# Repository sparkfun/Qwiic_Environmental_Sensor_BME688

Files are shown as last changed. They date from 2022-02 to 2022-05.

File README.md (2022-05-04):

SparkFun Environmental Sensor - BME688 (Qwiic)
========================================

SparkFun Environmental Sensor - BME688 (Qwiic) (https://www.sparkfun.com/products/19096)

[*SparkFun Environmental Sensor - BME688 (Qwiic) (SEN-19096)*](https://www.sparkfun.com/products/19096)

The SparkFun Environmental Sensor - BME688 (Qwiic) is a breakout board that combines a gas scanning sensor with temperature, humidity, and barometric pressure sensing for a complete environmental sensor in a single package. The gas sensor on the BME688 can detect a wide variety of volatile organic compounds (VOCs), volatile sulfur compounds (VSCs), and other gases such as carbon monoxide and hydrogen in the part per billion (ppb) range. Combine that with precise temperature, humidity, and barometric pressure and the BME688 can work as a completely standalone environmental sensor all in a 1in. x 1in. breakout!

The sensor communicates via either I2C or SPI. We've broken out the I2C pins to our Qwiic system so no soldering is required to connect it to the rest of your system but if you would prefer, both the I2C and SPI pins are also broken out to standard 0.1in.-spaced pins.

**Note:** While this sensor can be used with the BME AI-Studio and BSEC2 Arduino library; it is recommended for the AI functionality, users purchase the BME688 Evaluation Board (Coming Soon) for ease of use.

<p><div class="alert alert-warning"><b>Important:</b> In order to avoid contamination of its gas scanning capabilities, DO NOT touch the metallic casing of the BME688 sensor. Please, handle with care.</div></p>

_The SparkFun [Qwiic connect system](https://www.sparkfun.com/qwiic) is an ecosystem of I2C sensors, actuators, shields and cables that make prototyping faster and less prone to error. All Qwiic-enabled boards use a common 1mm pitch, 4-pin JST connector. This reduces the amount of required PCB space, and polarized connections mean you can’t hook it up wrong._

Repository Contents
-------------------

* **/Test Sketches** - Engineer's Arduino example code
* **/Hardware** - Eagle design files (.brd, .sch)
* **/Hardware/Production** - Production panel files (.brd)

Documentation
--------------

* **[Datasheet](https://www.bosch-sensortec.com/media/boschsensortec/downloads/datasheets/bst-bme688-ds000.pdf)** - BME688 Datasheet
* **[Hookup Guide](https://learn.sparkfun.com/tutorials/1168)** - SparkFun Environmental Sensor Breakout - BME68x (Qwiic) Hookup Guide
* **Arduino Libraries:**
    * **[BME680 Arduino Library](https://github.com/SV-Zanshin/BME680)** - Arduino Library used in Hookup Guide
    * **[BME68x Arduino Library](https://github.com/BoschSensortec/Bosch-BME68x-Library)** - Bosch's Arduino Library for BME68x Sensors
    * **[BSEC2 Arduino Library](https://github.com/BoschSensortec/Bosch-BSEC2-Library)** - Bosch's Arduino Library for BME AI-Studio
* **BME AI Studio:**
    * **BME AI-Studio (Mac/Windows)** *(Download from [Bosch software page](https://www.bosch-sensortec.com/software-tools/software/bme688-software/))*
    * **[BME AI-Studio Manual](https://www.bosch-sensortec.com/media/boschsensortec/downloads/application_notes_1/bst-bme688-an001.pdf)** - User Manual for BME AI-Studio

Product Versions
----------------
* [SEN-19096](https://www.sparkfun.com/products/19096) -  initial release

License Information
-------------------

This product is _**open source**_! 

Please review the LICENSE.md file for license information. 

If you have any questions or concerns on licensing, please contact technical support on our [SparkFun forums](https://forum.sparkfun.com/viewforum.php?f=152).

Distributed as-is; no warranty is given.

- Your friends at SparkFun.

_<COLLABORATION CREDIT>_

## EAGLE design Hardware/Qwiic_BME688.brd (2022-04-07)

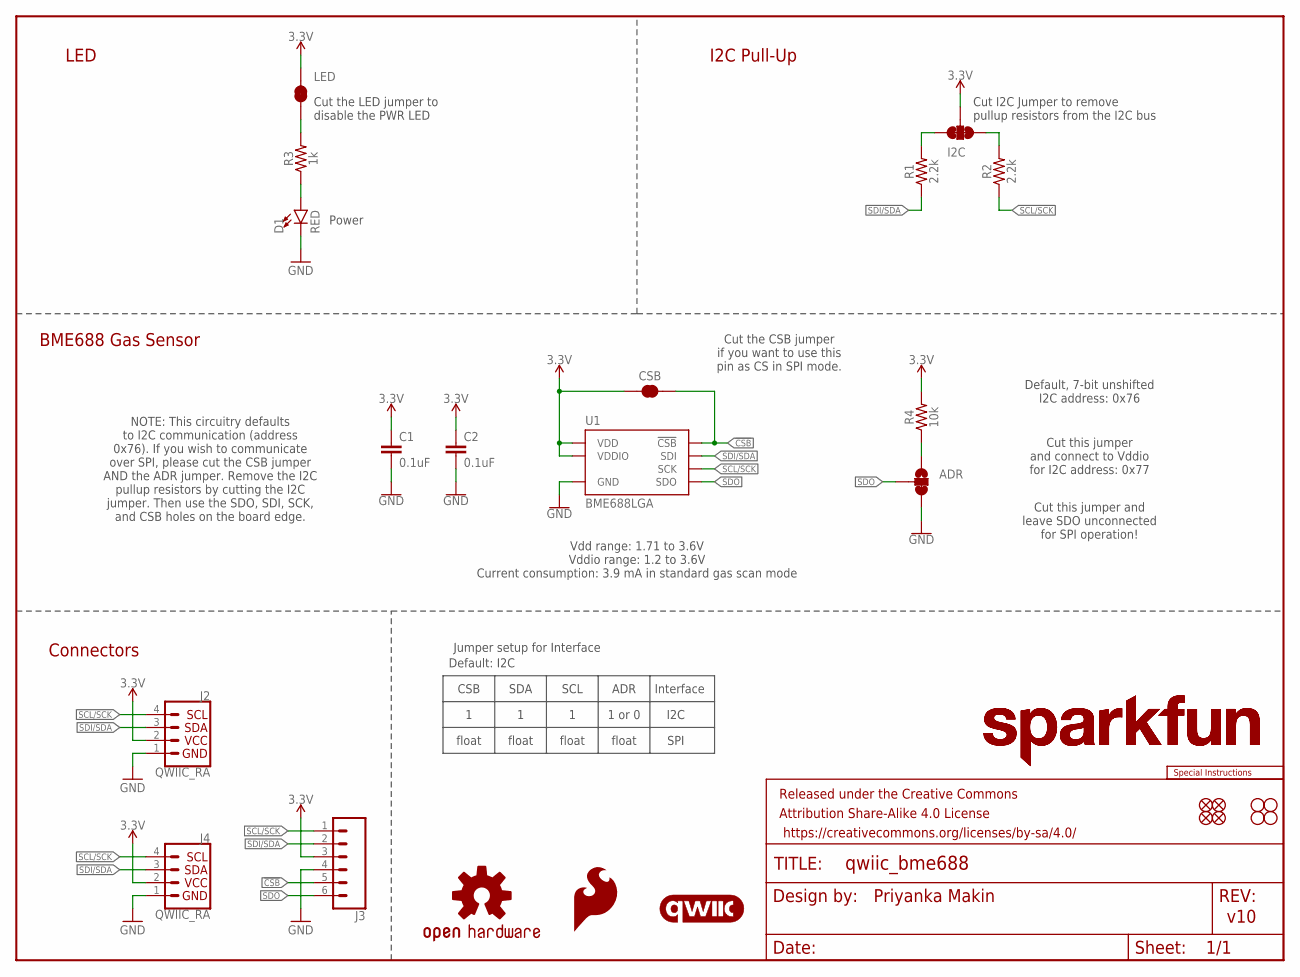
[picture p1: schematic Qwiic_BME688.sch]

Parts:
ADR: JUMPER-SMT_3_1-NC_TRACE_SILK; SMT-JUMPER_3_1-NC_TRACE_SILK
C1, C2: 0.1uF; 0603
CSB: JUMPER-SMT_2_NC_TRACE_SILK; SMT-JUMPER_2_NC_TRACE_SILK
D1: RED; LED-0603
FRAME1: FRAME-LETTER; CREATIVE_COMMONS
I2C: JUMPER-SMT_3_2-NC_TRACE_SILK; SMT-JUMPER_3_2-NC_TRACE_SILK
J2, J4: QWIIC_RA; JST04_1MM_RA
J3: CONN_06NO_SILK_NO_POP; 1X06_NO_SILK
JP1, JP2, JP5, JP6: FIDUCIALUFIDUCIAL; FIDUCIAL-MICRO
JP3, JP4, JP7, JP8: STAND-OFF
LED: JUMPER-SMT_2_NC_TRACE_SILK; SMT-JUMPER_2_NC_TRACE_SILK
LOGO1: SPECIAL_INSTRUCTIONS-ORDERING; ORDERING_INSTRUCTIONS
LOGO2: QWIIC_LOGO_5MM; QWIIC_5MM
LOGO3, LOGO6: SFE_LOGO_NAME.1_INCH; SFE_LOGO_NAME_.1
LOGO4: SFE_LOGO_FLAME.1_INCH; SFE_LOGO_FLAME_.1
LOGO5: OSHW-LOGOS; OSHW-LOGO-S
R1, R2: 2.2k; 0603
R3: 1k; 0603
R4: 10k; 0603
U1: BME688LGA; LGA_8PIN

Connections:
3.3V: C1.1, C2.1, CSB.1, I2C.2, J2.2, J3.3, J4.2, LED.2, R4.2, U1.6 (VDDIO), U1.8 (VDD)
!CSB!: CSB.2, J3.5, U1.2 (!CSB!)
GND: ADR.3, C1.2, C2.2, D1.C, J2.1, J3.4, J4.1, U1.1 (GND), U1.7 (GND)
unnamed: LED.1, R3.2
unnamed: I2C.3, R1.2
unnamed: D1.A, R3.1
unnamed: I2C.1, R2.2
unnamed: ADR.1, R4.1
SCL/SCK: J2.4, J3.1, J4.4, R2.1, U1.4 (SCK)
SDI/SDA: J2.3, J3.2, J4.3, R1.1, U1.3 (SDI)
SDO: ADR.2, J3.6, U1.5 (SDO)

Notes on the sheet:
v10
Default, 7-bit unshifted I2C address: 0x76
Power
I2C Pull-Up
BME688 Gas Sensor
Connectors
Cut the LED jumper to disable the PWR LED
Cut I2C Jumper to remove pullup resistors from the I2C bus
LED
Priyanka Makin
Vdd range: 1.71 to 3.6V Vddio range: 1.2 to 3.6V Current consumption: 3.9 mA in standard gas scan mode
Cut this jumper and connect to Vddio for I2C address: 0x77
Cut this jumper and leave SDO unconnected for SPI operation!
Cut the CSB jumper if you want to use this pin as CS in SPI mode.
NOTE: This circuitry defaults to I2C communication (address 0x76). If you wish to communicate over SPI, please cut the CSB jumper AND the ADR jumper. Remove the I2C pullup resistors by cutting the I2C jumper. Then use the SDO, SDI, SCK, and CSB holes on the board edge.
SCL
CSB
ADR
1 or 0
float
Interface
I2C
SPI
SDA
Jumper setup for Interface
Default: I2C

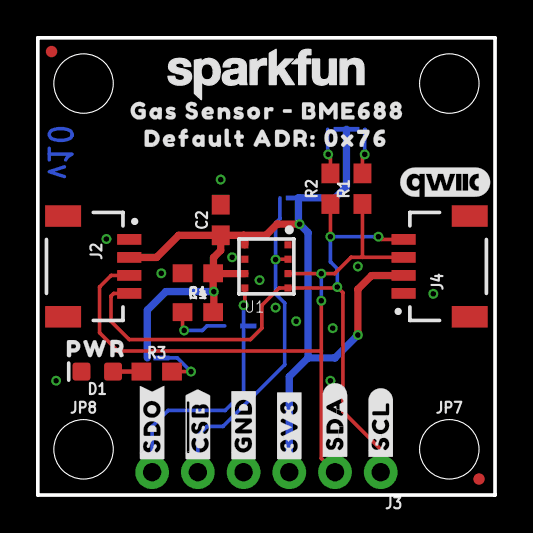
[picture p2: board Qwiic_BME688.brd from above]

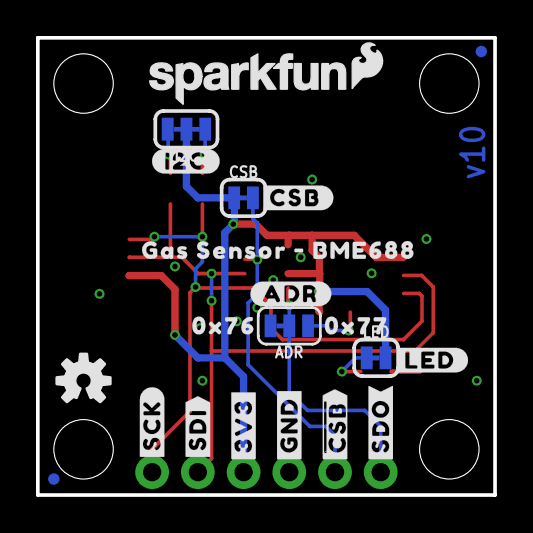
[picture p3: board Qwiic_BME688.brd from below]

Board: 2 copper layers, 25.4 x 25.4 mm, 52 parts (22 on the bottom side), 11 nets.

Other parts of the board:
U$1, U$33: #GND#0
U$2, U$16: #SDO#0
U$3: #CSB#0
U$5: PWR0
U$6: #I2C#0
U$7, U$10: GAS_SENSOR_#_BME6880
U$8: #LED#0
U$9: 0X760
U$11: #ADR#0
U$12: DEFAULT_ADR#_0X760
U$13: 0X770
U$14, U$15: #3V3#0
U$19: #SDI#0
U$20: #SCK#0
U$21, U$22: ##CSB##0
U$35: #SDA#0
U$36: #SCL#0

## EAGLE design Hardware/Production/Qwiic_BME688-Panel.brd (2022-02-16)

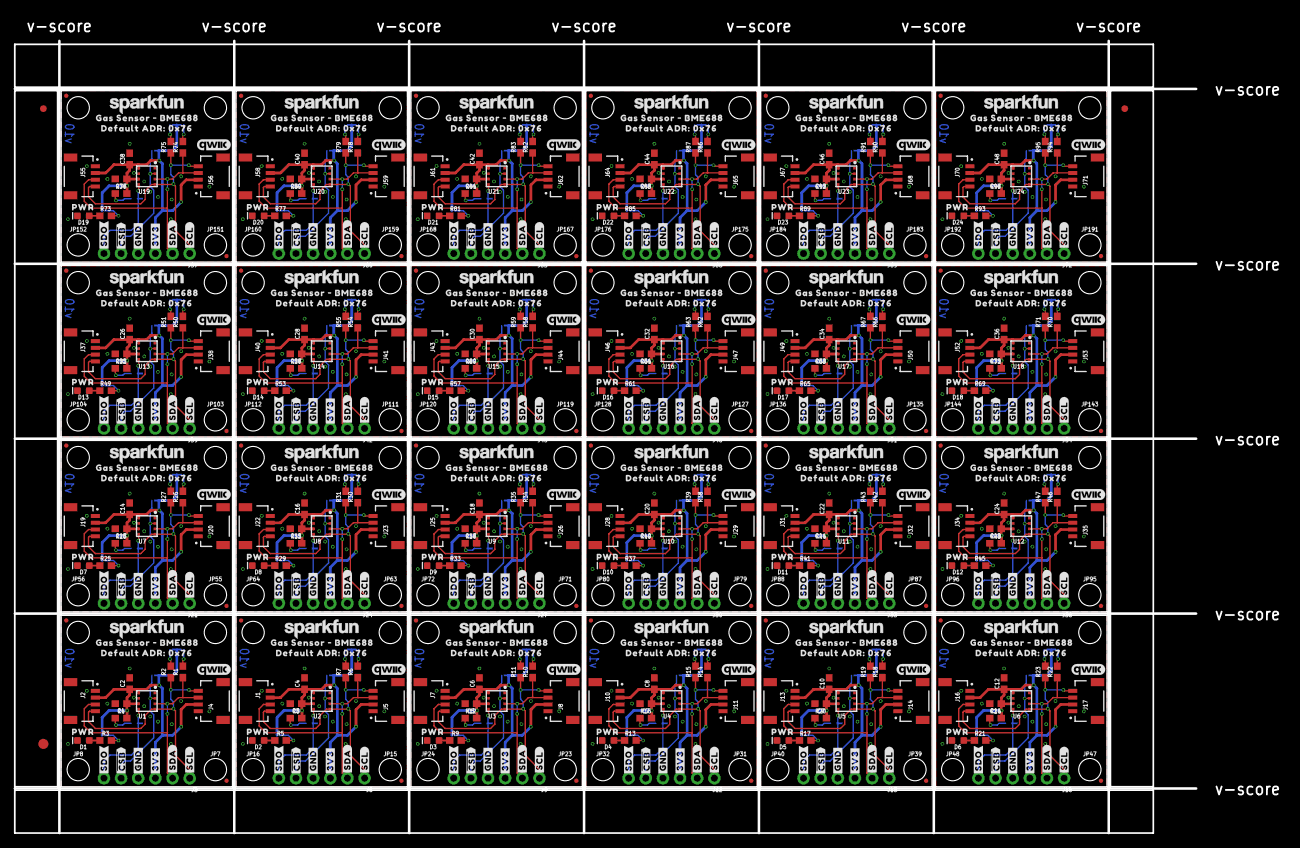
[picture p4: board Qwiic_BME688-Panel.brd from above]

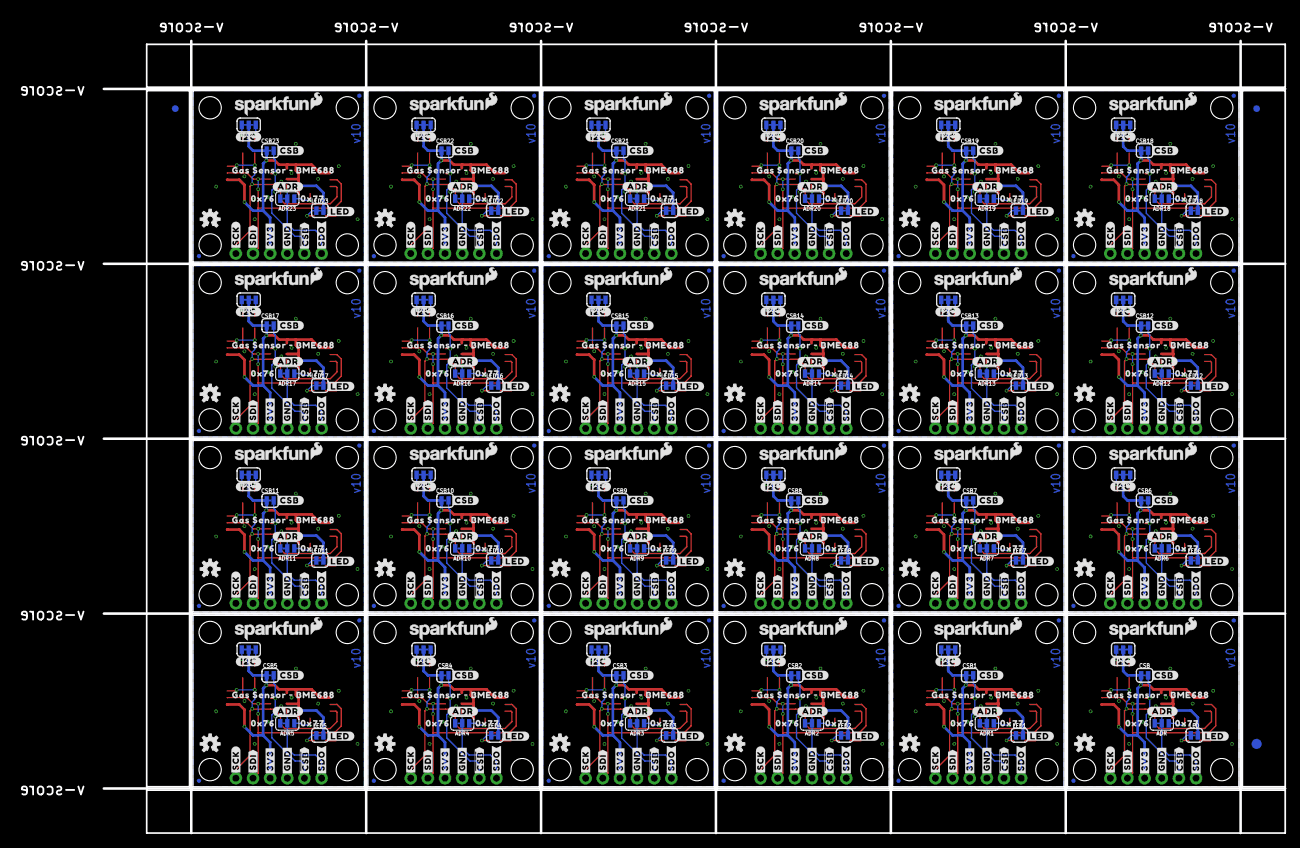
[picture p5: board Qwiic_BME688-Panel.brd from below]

Board: 2 copper layers, 175.0 x 117.3 mm, 1206 parts (531 on the bottom side), 264 nets.

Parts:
ADR, ADR1, ADR2, ADR3, ADR4, ADR5, ADR6, ADR7, ADR8, ADR9, ADR10, ADR11, ADR12, ADR13, ADR14, ADR15, ADR16, ADR17, ADR18, ADR19, ADR20, ADR21, ADR22, ADR23: JUMPER-SMT_3_1-NC_TRACE_SILK; SMT-JUMPER_3_1-NC_TRACE_SILK
C1, C2, C3, C4, C5, C6, C7, C8, C9, C10, C11, C12, C13, C14, C15, C16, C17, C18, C19, C20, C21, C22, C23, C24, C25, C26, C27, C28, C29, C30, C31, C32, C33, C34, C35, C36, C37, C38, C39, C40, C41, C42, C43, C44, C45, C46, C47, C48: 0.1uF; 0603
CSB, CSB1, CSB2, CSB3, CSB4, CSB5, CSB6, CSB7, CSB8, CSB9, CSB10, CSB11, CSB12, CSB13, CSB14, CSB15, CSB16, CSB17, CSB18, CSB19, CSB20, CSB21, CSB22, CSB23: JUMPER-SMT_2_NC_TRACE_SILK; SMT-JUMPER_2_NC_TRACE_SILK
D1, D2, D3, D4, D5, D6, D7, D8, D9, D10, D11, D12, D13, D14, D15, D16, D17, D18, D19, D20, D21, D22, D23, D24: RED; LED-0603
E$1, E$2, E$3, E$4: FIDUCIAL-1X2
E$5, E$6: FIDUCIAL-1.5X3
I2C, I2C1, I2C2, I2C3, I2C4, I2C5, I2C6, I2C7, I2C8, I2C9, I2C10, I2C11, I2C12, I2C13, I2C14, I2C15, I2C16, I2C17, I2C18, I2C19, I2C20, I2C21, I2C22, I2C23: JUMPER-SMT_3_2-NC_TRACE_SILK; SMT-JUMPER_3_2-NC_TRACE_SILK
J1, J2, J4, J5, J7, J8, J10, J11, J13, J14, J16, J17, J19, J20, J22, J23, J25, J26, J28, J29, J31, J32, J34, J35, J37, J38, J40, J41, J43, J44, J46, J47, J49, J50, J52, J53, J55, J56, J58, J59, J61, J62, J64, J65, J67, J68, J70, J71: QWIIC_RA; JST04_1MM_RA
J3, J6, J9, J12, J15, J18, J21, J24, J27, J30, J33, J36, J39, J42, J45, J48, J51, J54, J57, J60, J63, J66, J69, J72: 1X06_NO_SILK
JP1, JP2, JP5, JP6, JP11, JP12, JP13, JP14, JP19, JP20, JP21, JP22, JP27, JP28, JP29, JP30, JP35, JP36, JP37, JP38, JP43, JP44, JP45, JP46, JP51, JP52, JP53, JP54, JP59, JP60, JP61, JP62, JP67, JP68, JP69, JP70, JP75, JP76, JP77, JP78, JP83, JP84, JP85, JP86, JP91, JP92, JP93, JP94, JP99, JP100, JP101, JP102, JP107, JP108, JP109, JP110, JP115, JP116, JP117, JP118, JP123, JP124, JP125, JP126, JP131, JP132, JP133, JP134, JP139, JP140, JP141, JP142, JP147, JP148, JP149, JP150, JP155, JP156, JP157, JP158, JP163, JP164, JP165, JP166, JP171, JP172, JP173, JP174, JP179, JP180, JP181, JP182, JP187, JP188, JP189, JP190: FIDUCIALUFIDUCIAL; FIDUCIAL-MICRO
JP3, JP4, JP7, JP8, JP9, JP10, JP15, JP16, JP17, JP18, JP23, JP24, JP25, JP26, JP31, JP32, JP33, JP34, JP39, JP40, JP41, JP42, JP47, JP48, JP49, JP50, JP55, JP56, JP57, JP58, JP63, JP64, JP65, JP66, JP71, JP72, JP73, JP74, JP79, JP80, JP81, JP82, JP87, JP88, JP89, JP90, JP95, JP96, JP97, JP98, JP103, JP104, JP105, JP106, JP111, JP112, JP113, JP114, JP119, JP120, JP121, JP122, JP127, JP128, JP129, JP130, JP135, JP136, JP137, JP138, JP143, JP144, JP145, JP146, JP151, JP152, JP153, JP154, JP159, JP160, JP161, JP162, JP167, JP168, JP169, JP170, JP175, JP176, JP177, JP178, JP183, JP184, JP185, JP186, JP191, JP192: STAND-OFF
LED, LED1, LED2, LED3, LED4, LED5, LED6, LED7, LED8, LED9, LED10, LED11, LED12, LED13, LED14, LED15, LED16, LED17, LED18, LED19, LED20, LED21, LED22, LED23: JUMPER-SMT_2_NC_TRACE_SILK; SMT-JUMPER_2_NC_TRACE_SILK
LOGO1, LOGO5, LOGO11, LOGO16, LOGO21, LOGO26, LOGO31, LOGO36, LOGO41, LOGO46, LOGO51, LOGO56, LOGO61, LOGO66, LOGO71, LOGO76, LOGO81, LOGO86, LOGO91, LOGO96, LOGO101, LOGO106, LOGO111, LOGO116: OSHW-LOGOS; OSHW-LOGO-S
LOGO2, LOGO7, LOGO12, LOGO17, LOGO22, LOGO27, LOGO32, LOGO37, LOGO42, LOGO47, LOGO52, LOGO57, LOGO62, LOGO67, LOGO72, LOGO77, LOGO82, LOGO87, LOGO92, LOGO97, LOGO102, LOGO107, LOGO112, LOGO117: QWIIC_LOGO_5MM; QWIIC_5MM
LOGO3, LOGO6, LOGO8, LOGO10, LOGO13, LOGO15, LOGO18, LOGO20, LOGO23, LOGO25, LOGO28, LOGO30, LOGO33, LOGO35, LOGO38, LOGO40, LOGO43, LOGO45, LOGO48, LOGO50, LOGO53, LOGO55, LOGO58, LOGO60, LOGO63, LOGO65, LOGO68, LOGO70, LOGO73, LOGO75, LOGO78, LOGO80, LOGO83, LOGO85, LOGO88, LOGO90, LOGO93, LOGO95, LOGO98, LOGO100, LOGO103, LOGO105, LOGO108, LOGO110, LOGO113, LOGO115, LOGO118, LOGO120: SFE_LOGO_NAME.1_INCH; SFE_LOGO_NAME_.1
LOGO4, LOGO9, LOGO14, LOGO19, LOGO24, LOGO29, LOGO34, LOGO39, LOGO44, LOGO49, LOGO54, LOGO59, LOGO64, LOGO69, LOGO74, LOGO79, LOGO84, LOGO89, LOGO94, LOGO99, LOGO104, LOGO109, LOGO114, LOGO119: SFE_LOGO_FLAME.1_INCH; SFE_LOGO_FLAME_.1
R1, R2, R6, R7, R10, R11, R14, R15, R18, R19, R22, R23, R26, R27, R30, R31, R34, R35, R38, R39, R42, R43, R46, R47, R50, R51, R54, R55, R58, R59, R62, R63, R66, R67, R70, R71, R74, R75, R78, R79, R82, R83, R86, R87, R90, R91, R94, R95: 2.2k; 0603
R3, R5, R9, R13, R17, R21, R25, R29, R33, R37, R41, R45, R49, R53, R57, R61, R65, R69, R73, R77, R81, R85, R89, R93: 1k; 0603
R4, R8, R12, R16, R20, R24, R28, R32, R36, R40, R44, R48, R52, R56, R60, R64, R68, R72, R76, R80, R84, R88, R92, R96: 10k; 0603
U1, U2, U3, U4, U5, U6, U7, U8, U9, U10, U11, U12, U13, U14, U15, U16, U17, U18, U19, U20, U21, U22, U23, U24: BME688LGA; LGA_8PIN
U$1, U$4, U$23, U$33, U$45, U$48, U$67, U$70, U$89, U$92, U$111, U$114, U$133, U$136, U$155, U$158, U$177, U$180, U$199, U$202, U$221, U$224, U$243, U$246, U$265, U$268, U$287, U$290, U$309, U$312, U$331, U$334, U$353, U$356, U$375, U$378, U$397, U$400, U$419, U$422, U$441, U$444, U$463, U$466, U$485, U$488, U$507, U$510: #GND#0
U$2, U$16, U$38, U$39, U$60, U$61, U$82, U$83, U$104, U$105, U$126, U$127, U$148, U$149, U$170, U$171, U$192, U$193, U$214, U$215, U$236, U$237, U$258, U$259, U$280, U$281, U$302, U$303, U$324, U$325, U$346, U$347, U$368, U$369, U$390, U$391, U$412, U$413, U$434, U$435, U$456, U$457, U$478, U$479, U$500, U$501, U$522, U$523: #SDO#0
U$3, U$42, U$64, U$86, U$108, U$130, U$152, U$174, U$196, U$218, U$240, U$262, U$284, U$306, U$328, U$350, U$372, U$394, U$416, U$438, U$460, U$482, U$504, U$526: #CSB#0
U$5, U$24, U$49, U$71, U$93, U$115, U$137, U$159, U$181, U$203, U$225, U$247, U$269, U$291, U$313, U$335, U$357, U$379, U$401, U$423, U$445, U$467, U$489, U$511: PWR0
U$6, U$29, U$54, U$76, U$98, U$120, U$142, U$164, U$186, U$208, U$230, U$252, U$274, U$296, U$318, U$340, U$362, U$384, U$406, U$428, U$450, U$472, U$494, U$516: #I2C#0
U$7, U$10, U$25, U$27, U$50, U$52, U$72, U$74, U$94, U$96, U$116, U$118, U$138, U$140, U$160, U$162, U$182, U$184, U$204, U$206, U$226, U$228, U$248, U$250, U$270, U$272, U$292, U$294, U$314, U$316, U$336, U$338, U$358, U$360, U$380, U$382, U$402, U$404, U$424, U$426, U$446, U$448, U$468, U$470, U$490, U$492, U$512, U$514: GAS_SENSOR_#_BME6880
U$8, U$28, U$53, U$75, U$97, U$119, U$141, U$163, U$185, U$207, U$229, U$251, U$273, U$295, U$317, U$339, U$361, U$383, U$405, U$427, U$449, U$471, U$493, U$515: #LED#0
U$9, U$31, U$56, U$78, U$100, U$122, U$144, U$166, U$188, U$210, U$232, U$254, U$276, U$298, U$320, U$342, U$364, U$386, U$408, U$430, U$452, U$474, U$496, U$518: 0X760
U$11, U$26, U$51, U$73, U$95, U$117, U$139, U$161, U$183, U$205, U$227, U$249, U$271, U$293, U$315, U$337, U$359, U$381, U$403, U$425, U$447, U$469, U$491, U$513: #ADR#0
U$12, U$30, U$55, U$77, U$99, U$121, U$143, U$165, U$187, U$209, U$231, U$253, U$275, U$297, U$319, U$341, U$363, U$385, U$407, U$429, U$451, U$473, U$495, U$517: DEFAULT_ADR#_0X760
U$13, U$32, U$57, U$79, U$101, U$123, U$145, U$167, U$189, U$211, U$233, U$255, U$277, U$299, U$321, U$343, U$365, U$387, U$409, U$431, U$453, U$475, U$497, U$519: 0X770
U$14, U$15, U$34, U$37, U$58, U$59, U$80, U$81, U$102, U$103, U$124, U$125, U$146, U$147, U$168, U$169, U$190, U$191, U$212, U$213, U$234, U$235, U$256, U$257, U$278, U$279, U$300, U$301, U$322, U$323, U$344, U$345, U$366, U$367, U$388, U$389, U$410, U$411, U$432, U$433, U$454, U$455, U$476, U$477, U$498, U$499, U$520, U$521: #3V3#0
U$17, U$35, U$46, U$68, U$90, U$112, U$134, U$156, U$178, U$200, U$222, U$244, U$266, U$288, U$310, U$332, U$354, U$376, U$398, U$420, U$442, U$464, U$486, U$508: #SDA#0
U$18, U$36, U$47, U$69, U$91, U$113, U$135, U$157, U$179, U$201, U$223, U$245, U$267, U$289, U$311, U$333, U$355, U$377, U$399, U$421, U$443, U$465, U$487, U$509: #SCL#0
U$19, U$40, U$62, U$84, U$106, U$128, U$150, U$172, U$194, U$216, U$238, U$260, U$282, U$304, U$326, U$348, U$370, U$392, U$414, U$436, U$458, U$480, U$502, U$524: #SDI#0
U$20, U$41, U$63, U$85, U$107, U$129, U$151, U$173, U$195, U$217, U$239, U$261, U$283, U$305, U$327, U$349, U$371, U$393, U$415, U$437, U$459, U$481, U$503, U$525: #SCK#0
U$21, U$22, U$43, U$44, U$65, U$66, U$87, U$88, U$109, U$110, U$131, U$132, U$153, U$154, U$175, U$176, U$197, U$198, U$219, U$220, U$241, U$242, U$263, U$264, U$285, U$286, U$307, U$308, U$329, U$330, U$351, U$352, U$373, U$374, U$395, U$396, U$417, U$418, U$439, U$440, U$461, U$462, U$483, U$484, U$505, U$506, U$527, U$528: ##CSB##0

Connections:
3.3V: C1.1, C2.1, CSB.1, I2C.2, J2.2, J3.3, J4.2, LED.2, R4.2, U1.6, U1.8
3.3V1: C3.1, C4.1, CSB1.1, I2C1.2, J1.2, J5.2, J6.3, LED1.2, R8.2, U2.6, U2.8
3.3V2: C5.1, C6.1, CSB2.1, I2C2.2, J7.2, J8.2, J9.3, LED2.2, R12.2, U3.6, U3.8
3.3V3: C7.1, C8.1, CSB3.1, I2C3.2, J10.2, J11.2, J12.3, LED3.2, R16.2, U4.6, U4.8
3.3V4: C9.1, C10.1, CSB4.1, I2C4.2, J13.2, J14.2, J15.3, LED4.2, R20.2, U5.6, U5.8
3.3V5: C11.1, C12.1, CSB5.1, I2C5.2, J16.2, J17.2, J18.3, LED5.2, R24.2, U6.6, U6.8
3.3V6: C13.1, C14.1, CSB6.1, I2C6.2, J19.2, J20.2, J21.3, LED6.2, R28.2, U7.6, U7.8
3.3V7: C15.1, C16.1, CSB7.1, I2C7.2, J22.2, J23.2, J24.3, LED7.2, R32.2, U8.6, U8.8
3.3V8: C17.1, C18.1, CSB8.1, I2C8.2, J25.2, J26.2, J27.3, LED8.2, R36.2, U9.6, U9.8
3.3V9: C19.1, C20.1, CSB9.1, I2C9.2, J28.2, J29.2, J30.3, LED9.2, R40.2, U10.6, U10.8
3.3V10: C21.1, C22.1, CSB10.1, I2C10.2, J31.2, J32.2, J33.3, LED10.2, R44.2, U11.6, U11.8
3.3V11: C23.1, C24.1, CSB11.1, I2C11.2, J34.2, J35.2, J36.3, LED11.2, R48.2, U12.6, U12.8
3.3V12: C25.1, C26.1, CSB12.1, I2C12.2, J37.2, J38.2, J39.3, LED12.2, R52.2, U13.6, U13.8
3.3V13: C27.1, C28.1, CSB13.1, I2C13.2, J40.2, J41.2, J42.3, LED13.2, R56.2, U14.6, U14.8
3.3V14: C29.1, C30.1, CSB14.1, I2C14.2, J43.2, J44.2, J45.3, LED14.2, R60.2, U15.6, U15.8
3.3V15: C31.1, C32.1, CSB15.1, I2C15.2, J46.2, J47.2, J48.3, LED15.2, R64.2, U16.6, U16.8
3.3V16: C33.1, C34.1, CSB16.1, I2C16.2, J49.2, J50.2, J51.3, LED16.2, R68.2, U17.6, U17.8
3.3V17: C35.1, C36.1, CSB17.1, I2C17.2, J52.2, J53.2, J54.3, LED17.2, R72.2, U18.6, U18.8
3.3V18: C37.1, C38.1, CSB18.1, I2C18.2, J55.2, J56.2, J57.3, LED18.2, R76.2, U19.6, U19.8
3.3V19: C39.1, C40.1, CSB19.1, I2C19.2, J58.2, J59.2, J60.3, LED19.2, R80.2, U20.6, U20.8
3.3V20: C41.1, C42.1, CSB20.1, I2C20.2, J61.2, J62.2, J63.3, LED20.2, R84.2, U21.6, U21.8
3.3V21: C43.1, C44.1, CSB21.1, I2C21.2, J64.2, J65.2, J66.3, LED21.2, R88.2, U22.6, U22.8
3.3V22: C45.1, C46.1, CSB22.1, I2C22.2, J67.2, J68.2, J69.3, LED22.2, R92.2, U23.6, U23.8
3.3V23: C47.1, C48.1, CSB23.1, I2C23.2, J70.2, J71.2, J72.3, LED23.2, R96.2, U24.6, U24.8
!CSB!: CSB.2, J3.5, U1.2
!CSB!1: CSB1.2, J6.5, U2.2
!CSB!2: CSB2.2, J9.5, U3.2
!CSB!3: CSB3.2, J12.5, U4.2
!CSB!4: CSB4.2, J15.5, U5.2
!CSB!5: CSB5.2, J18.5, U6.2
!CSB!6: CSB6.2, J21.5, U7.2
!CSB!7: CSB7.2, J24.5, U8.2
!CSB!8: CSB8.2, J27.5, U9.2
!CSB!9: CSB9.2, J30.5, U10.2
!CSB!10: CSB10.2, J33.5, U11.2
!CSB!11: CSB11.2, J36.5, U12.2
!CSB!12: CSB12.2, J39.5, U13.2
!CSB!13: CSB13.2, J42.5, U14.2
!CSB!14: CSB14.2, J45.5, U15.2
!CSB!15: CSB15.2, J48.5, U16.2
!CSB!16: CSB16.2, J51.5, U17.2
!CSB!17: CSB17.2, J54.5, U18.2
!CSB!18: CSB18.2, J57.5, U19.2
!CSB!19: CSB19.2, J60.5, U20.2
!CSB!20: CSB20.2, J63.5, U21.2
!CSB!21: CSB21.2, J66.5, U22.2
!CSB!22: CSB22.2, J69.5, U23.2
!CSB!23: CSB23.2, J72.5, U24.2
GND: ADR.3, C1.2, C2.2, D1.C, J2.1, J3.4, J4.1, U1.1, U1.7
GND1: ADR1.3, C3.2, C4.2, D2.C, J1.1, J5.1, J6.4, U2.1, U2.7
GND2: ADR2.3, C5.2, C6.2, D3.C, J7.1, J8.1, J9.4, U3.1, U3.7
GND3: ADR3.3, C7.2, C8.2, D4.C, J10.1, J11.1, J12.4, U4.1, U4.7
GND4: ADR4.3, C9.2, C10.2, D5.C, J13.1, J14.1, J15.4, U5.1, U5.7
GND5: ADR5.3, C11.2, C12.2, D6.C, J16.1, J17.1, J18.4, U6.1, U6.7
GND6: ADR6.3, C13.2, C14.2, D7.C, J19.1, J20.1, J21.4, U7.1, U7.7
GND7: ADR7.3, C15.2, C16.2, D8.C, J22.1, J23.1, J24.4, U8.1, U8.7
GND8: ADR8.3, C17.2, C18.2, D9.C, J25.1, J26.1, J27.4, U9.1, U9.7
GND9: ADR9.3, C19.2, C20.2, D10.C, J28.1, J29.1, J30.4, U10.1, U10.7
GND10: ADR10.3, C21.2, C22.2, D11.C, J31.1, J32.1, J33.4, U11.1, U11.7
GND11: ADR11.3, C23.2, C24.2, D12.C, J34.1, J35.1, J36.4, U12.1, U12.7
GND12: ADR12.3, C25.2, C26.2, D13.C, J37.1, J38.1, J39.4, U13.1, U13.7
GND13: ADR13.3, C27.2, C28.2, D14.C, J40.1, J41.1, J42.4, U14.1, U14.7
GND14: ADR14.3, C29.2, C30.2, D15.C, J43.1, J44.1, J45.4, U15.1, U15.7
GND15: ADR15.3, C31.2, C32.2, D16.C, J46.1, J47.1, J48.4, U16.1, U16.7
GND16: ADR16.3, C33.2, C34.2, D17.C, J49.1, J50.1, J51.4, U17.1, U17.7
GND17: ADR17.3, C35.2, C36.2, D18.C, J52.1, J53.1, J54.4, U18.1, U18.7
GND18: ADR18.3, C37.2, C38.2, D19.C, J55.1, J56.1, J57.4, U19.1, U19.7
GND19: ADR19.3, C39.2, C40.2, D20.C, J58.1, J59.1, J60.4, U20.1, U20.7
GND20: ADR20.3, C41.2, C42.2, D21.C, J61.1, J62.1, J63.4, U21.1, U21.7
GND21: ADR21.3, C43.2, C44.2, D22.C, J64.1, J65.1, J66.4, U22.1, U22.7
GND22: ADR22.3, C45.2, C46.2, D23.C, J67.1, J68.1, J69.4, U23.1, U23.7
GND23: ADR23.3, C47.2, C48.2, D24.C, J70.1, J71.1, J72.4, U24.1, U24.7
unnamed: LED.1, R3.2
unnamed: I2C.3, R1.2
unnamed: D1.A, R3.1
unnamed: I2C.1, R2.2
unnamed: ADR.1, R4.1
unnamed: D2.A, R5.1
unnamed: LED1.1, R5.2
unnamed: I2C1.3, R6.2
unnamed: I2C1.1, R7.2
unnamed: ADR1.1, R8.1
unnamed: D3.A, R9.1
unnamed: LED2.1, R9.2
unnamed: I2C2.3, R10.2
unnamed: I2C2.1, R11.2
unnamed: ADR2.1, R12.1
unnamed: D4.A, R13.1
unnamed: LED3.1, R13.2
unnamed: I2C3.3, R14.2
unnamed: I2C3.1, R15.2
unnamed: ADR3.1, R16.1
unnamed: D5.A, R17.1
unnamed: LED4.1, R17.2
unnamed: I2C4.3, R18.2
unnamed: I2C4.1, R19.2
unnamed: ADR4.1, R20.1
unnamed: D6.A, R21.1
unnamed: LED5.1, R21.2
unnamed: I2C5.3, R22.2
unnamed: I2C5.1, R23.2
unnamed: ADR5.1, R24.1
unnamed: D7.A, R25.1
unnamed: LED6.1, R25.2
unnamed: I2C6.3, R26.2
unnamed: I2C6.1, R27.2
unnamed: ADR6.1, R28.1
unnamed: D8.A, R29.1
unnamed: LED7.1, R29.2
unnamed: I2C7.3, R30.2
unnamed: I2C7.1, R31.2
unnamed: ADR7.1, R32.1
unnamed: D9.A, R33.1
unnamed: LED8.1, R33.2
unnamed: I2C8.3, R34.2
unnamed: I2C8.1, R35.2
unnamed: ADR8.1, R36.1
unnamed: D10.A, R37.1
unnamed: LED9.1, R37.2
unnamed: I2C9.3, R38.2
unnamed: I2C9.1, R39.2
unnamed: ADR9.1, R40.1
unnamed: D11.A, R41.1
unnamed: LED10.1, R41.2
unnamed: I2C10.3, R42.2
unnamed: I2C10.1, R43.2
unnamed: ADR10.1, R44.1
unnamed: D12.A, R45.1
unnamed: LED11.1, R45.2
unnamed: I2C11.3, R46.2
unnamed: I2C11.1, R47.2
unnamed: ADR11.1, R48.1
unnamed: D13.A, R49.1
unnamed: LED12.1, R49.2
unnamed: I2C12.3, R50.2
unnamed: I2C12.1, R51.2
unnamed: ADR12.1, R52.1
unnamed: D14.A, R53.1
unnamed: LED13.1, R53.2
unnamed: I2C13.3, R54.2
unnamed: I2C13.1, R55.2
unnamed: ADR13.1, R56.1
unnamed: D15.A, R57.1
unnamed: LED14.1, R57.2
unnamed: I2C14.3, R58.2
unnamed: I2C14.1, R59.2
unnamed: ADR14.1, R60.1
unnamed: D16.A, R61.1
unnamed: LED15.1, R61.2
unnamed: I2C15.3, R62.2
unnamed: I2C15.1, R63.2
unnamed: ADR15.1, R64.1
unnamed: D17.A, R65.1
unnamed: LED16.1, R65.2
unnamed: I2C16.3, R66.2
unnamed: I2C16.1, R67.2
unnamed: ADR16.1, R68.1
unnamed: D18.A, R69.1
unnamed: LED17.1, R69.2
unnamed: I2C17.3, R70.2
unnamed: I2C17.1, R71.2
unnamed: ADR17.1, R72.1
unnamed: D19.A, R73.1
unnamed: LED18.1, R73.2
unnamed: I2C18.3, R74.2
unnamed: I2C18.1, R75.2
unnamed: ADR18.1, R76.1
unnamed: D20.A, R77.1
unnamed: LED19.1, R77.2
unnamed: I2C19.3, R78.2
unnamed: I2C19.1, R79.2
unnamed: ADR19.1, R80.1
unnamed: D21.A, R81.1
unnamed: LED20.1, R81.2
unnamed: I2C20.3, R82.2
unnamed: I2C20.1, R83.2
unnamed: ADR20.1, R84.1
unnamed: D22.A, R85.1
unnamed: LED21.1, R85.2
unnamed: I2C21.3, R86.2
unnamed: I2C21.1, R87.2
unnamed: ADR21.1, R88.1
unnamed: D23.A, R89.1
unnamed: LED22.1, R89.2
unnamed: I2C22.3, R90.2
unnamed: I2C22.1, R91.2
unnamed: ADR22.1, R92.1
unnamed: D24.A, R93.1
unnamed: LED23.1, R93.2
unnamed: I2C23.3, R94.2
unnamed: I2C23.1, R95.2
unnamed: ADR23.1, R96.1
SCL/SCK: J2.4, J3.1, J4.4, R2.1, U1.4
SCL/SCK1: J1.4, J5.4, J6.1, R7.1, U2.4
SCL/SCK2: J7.4, J8.4, J9.1, R11.1, U3.4
SCL/SCK3: J10.4, J11.4, J12.1, R15.1, U4.4
SCL/SCK4: J13.4, J14.4, J15.1, R19.1, U5.4
SCL/SCK5: J16.4, J17.4, J18.1, R23.1, U6.4
SCL/SCK6: J19.4, J20.4, J21.1, R27.1, U7.4
SCL/SCK7: J22.4, J23.4, J24.1, R31.1, U8.4
SCL/SCK8: J25.4, J26.4, J27.1, R35.1, U9.4
SCL/SCK9: J28.4, J29.4, J30.1, R39.1, U10.4
SCL/SCK10: J31.4, J32.4, J33.1, R43.1, U11.4
SCL/SCK11: J34.4, J35.4, J36.1, R47.1, U12.4
SCL/SCK12: J37.4, J38.4, J39.1, R51.1, U13.4
SCL/SCK13: J40.4, J41.4, J42.1, R55.1, U14.4
SCL/SCK14: J43.4, J44.4, J45.1, R59.1, U15.4
SCL/SCK15: J46.4, J47.4, J48.1, R63.1, U16.4
SCL/SCK16: J49.4, J50.4, J51.1, R67.1, U17.4
SCL/SCK17: J52.4, J53.4, J54.1, R71.1, U18.4
SCL/SCK18: J55.4, J56.4, J57.1, R75.1, U19.4
SCL/SCK19: J58.4, J59.4, J60.1, R79.1, U20.4
SCL/SCK20: J61.4, J62.4, J63.1, R83.1, U21.4
SCL/SCK21: J64.4, J65.4, J66.1, R87.1, U22.4
SCL/SCK22: J67.4, J68.4, J69.1, R91.1, U23.4
SCL/SCK23: J70.4, J71.4, J72.1, R95.1, U24.4
SDA/PICO: J2.3, J3.2, J4.3, R1.1, U1.3
SDA/PICO1: J1.3, J5.3, J6.2, R6.1, U2.3
SDA/PICO2: J7.3, J8.3, J9.2, R10.1, U3.3
SDA/PICO3: J10.3, J11.3, J12.2, R14.1, U4.3
SDA/PICO4: J13.3, J14.3, J15.2, R18.1, U5.3
SDA/PICO5: J16.3, J17.3, J18.2, R22.1, U6.3
SDA/PICO6: J19.3, J20.3, J21.2, R26.1, U7.3
SDA/PICO7: J22.3, J23.3, J24.2, R30.1, U8.3
SDA/PICO8: J25.3, J26.3, J27.2, R34.1, U9.3
SDA/PICO9: J28.3, J29.3, J30.2, R38.1, U10.3
SDA/PICO10: J31.3, J32.3, J33.2, R42.1, U11.3
SDA/PICO11: J34.3, J35.3, J36.2, R46.1, U12.3
SDA/PICO12: J37.3, J38.3, J39.2, R50.1, U13.3
SDA/PICO13: J40.3, J41.3, J42.2, R54.1, U14.3
SDA/PICO14: J43.3, J44.3, J45.2, R58.1, U15.3
SDA/PICO15: J46.3, J47.3, J48.2, R62.1, U16.3
SDA/PICO16: J49.3, J50.3, J51.2, R66.1, U17.3
SDA/PICO17: J52.3, J53.3, J54.2, R70.1, U18.3
SDA/PICO18: J55.3, J56.3, J57.2, R74.1, U19.3
SDA/PICO19: J58.3, J59.3, J60.2, R78.1, U20.3
SDA/PICO20: J61.3, J62.3, J63.2, R82.1, U21.3
SDA/PICO21: J64.3, J65.3, J66.2, R86.1, U22.3
SDA/PICO22: J67.3, J68.3, J69.2, R90.1, U23.3
SDA/PICO23: J70.3, J71.3, J72.2, R94.1, U24.3
SDO/POCI: ADR.2, J3.6, U1.5
SDO/POCI1: ADR1.2, J6.6, U2.5
SDO/POCI2: ADR2.2, J9.6, U3.5
SDO/POCI3: ADR3.2, J12.6, U4.5
SDO/POCI4: ADR4.2, J15.6, U5.5
SDO/POCI5: ADR5.2, J18.6, U6.5
SDO/POCI6: ADR6.2, J21.6, U7.5
SDO/POCI7: ADR7.2, J24.6, U8.5
SDO/POCI8: ADR8.2, J27.6, U9.5
SDO/POCI9: ADR9.2, J30.6, U10.5
SDO/POCI10: ADR10.2, J33.6, U11.5
SDO/POCI11: ADR11.2, J36.6, U12.5
SDO/POCI12: ADR12.2, J39.6, U13.5
SDO/POCI13: ADR13.2, J42.6, U14.5
SDO/POCI14: ADR14.2, J45.6, U15.5
SDO/POCI15: ADR15.2, J48.6, U16.5
SDO/POCI16: ADR16.2, J51.6, U17.5
SDO/POCI17: ADR17.2, J54.6, U18.5
SDO/POCI18: ADR18.2, J57.6, U19.5
SDO/POCI19: ADR19.2, J60.6, U20.5
SDO/POCI20: ADR20.2, J63.6, U21.5
SDO/POCI21: ADR21.2, J66.6, U22.5
SDO/POCI22: ADR22.2, J69.6, U23.5
SDO/POCI23: ADR23.2, J72.6, U24.5

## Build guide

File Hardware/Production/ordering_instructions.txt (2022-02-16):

panel size, 169x117mm
PCB thickness, 1.6mm
number of layers, 2
soldermask color, Red
silkscreen color, White
oz copper, 1oz
finish, HASL lead free
stencils, top
pcs per panel, 24
min trace width, 0.2032mm / 0.0080in
min drill size, 0.3000mm / 0.0118in

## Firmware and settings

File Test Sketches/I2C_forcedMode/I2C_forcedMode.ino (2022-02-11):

/**
 * Copyright (C) 2021 Bosch Sensortec GmbH
 *
 * SPDX-License-Identifier: BSD-3-Clause
 * 
 */

#include "Arduino.h"
#include "bme68xLibrary.h"

#define I2C_ADDR 0x76

Bme68x bme;

/**
 * @brief Initializes the sensor and hardware settings
 */
void setup(void)
{
  Wire.begin(); // Join I2C bus
  Serial.begin(115200);
  
  while (!Serial)
    delay(10);
    
  // Initialize I2C operation
  bme.begin(I2C_ADDR, Wire);

  if(bme.checkStatus())
  {
    if (bme.checkStatus() == BME68X_ERROR)
    {
      Serial.println("Sensor error:" + bme.statusString());
      return;
    }
    else if (bme.checkStatus() == BME68X_WARNING)
    {
      Serial.println("Sensor Warning:" + bme.statusString());
    }
  }
  
  /* Set the default configuration for temperature, pressure and humidity */
  bme.setTPH();

  /* Set the heater configuration to 300 deg C for 100ms for Forced mode */
  bme.setHeaterProf(300, 100);

  Serial.println("TimeStamp(ms), Temperature(deg C), Pressure(Pa), Humidity(%), Gas resistance(ohm), Status");
}

void loop(void)
{
  bme68xData data;

  bme.setOpMode(BME68X_FORCED_MODE);
  delayMicroseconds(bme.getMeasDur());

  if (bme.fetchData())
  {
    bme.getData(data);
    Serial.println("Timestamp: " + String(millis()) + ", ");
    Serial.print("Temperature: " + String(data.temperature) + ", ");
    Serial.print("Pressure: " + String(data.pressure) + ", ");
    Serial.println("Humidity: " + String(data.humidity) + ", ");
    Serial.print("Gas: " + String(data.gas_resistance) + ", ");
    Serial.print("Status: ");
    Serial.println(data.status, HEX);
    Serial.println(); // New line
  }

  delay(1000);
}

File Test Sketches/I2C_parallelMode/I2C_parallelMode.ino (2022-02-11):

/**
 * Copyright (C) 2021 Bosch Sensortec GmbH
 *
 * SPDX-License-Identifier: BSD-3-Clause
 * 
 */

#include "Arduino.h"
#include "bme68xLibrary.h"

#define NEW_GAS_MEAS (BME68X_GASM_VALID_MSK | BME68X_HEAT_STAB_MSK | BME68X_NEW_DATA_MSK)
#define MEAS_DUR 140

#define I2C_ADDR 0x76 // Default I2C address for BME688

Bme68x bme;

/**
 * @brief Initializes the sensor and hardware settings
 */
void setup(void)
{
  Wire.begin();  // Join the I2C bus
  Serial.begin(115200);
  
  while (!Serial)
    delay(10);

  // Initialize I2C operation
  bme.begin(I2C_ADDR, Wire);

  if(bme.checkStatus())
  {
    if (bme.checkStatus() == BME68X_ERROR)
    {
      Serial.println("Sensor error:" + bme.statusString());
      //return;
      // Wait here if there's an error
      while(1);
    }
    else if (bme.checkStatus() == BME68X_WARNING)
    {
      Serial.println("Sensor Warning:" + bme.statusString());
      // Wait here if there's a warning
      while(1);
    }
  }
  
  /* Set the default configuratioSn for temperature, pressure and humidity */
  bme.setTPH();

  /* Heater temperature in degree Celsius */
  uint16_t tempProf[10] = { 320, 100, 100, 100, 200, 200, 200, 320, 320,
      320 };
  /* Multiplier to the shared heater duration */
  uint16_t mulProf[10] = { 5, 2, 10, 30, 5, 5, 5, 5, 5, 5 };
  /* Shared heating duration in milliseconds */
  uint16_t sharedHeatrDur = MEAS_DUR - (bme.getMeasDur(BME68X_PARALLEL_MODE) / 1000);

  bme.setHeaterProf(tempProf, mulProf, sharedHeatrDur, 10);
  bme.setOpMode(BME68X_PARALLEL_MODE);

  // For debugging
  Serial.println(bme.getOpMode());
  
  Serial.println("TimeStamp(ms), Temperature(deg C), Pressure(Pa), Humidity(%), Gas resistance(ohm), Status, Gas index");
}

void loop(void)
{
  bme68xData data;
  uint8_t nFieldsLeft = 0;

  /* data being fetched for every 140ms */
  delay(MEAS_DUR);

  if (bme.fetchData())
  {
    do
    {
      nFieldsLeft = bme.getData(data);
      if (data.status == NEW_GAS_MEAS)
      {
        Serial.println("Timestamp: " + String(millis()) + ", ");
        Serial.print("Temperature: " + String(data.temperature) + ", ");
        Serial.print("Pressure: " + String(data.pressure) + ", ");
        Serial.println("Humidity: " + String(data.humidity) + ", ");
        Serial.print("Gas: " + String(data.gas_resistance) + ", ");
        Serial.print("Status: ");
        Serial.print(data.status, HEX);
        Serial.println(", Index: " + String(data.gas_index));
        Serial.println(); // New line
      }
    } while (nFieldsLeft);
  }
}

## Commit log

2021-12-16 initial hardware commit
    [Qwiic_BME688.brd, Qwiic_BME688.sch]
2021-12-16 Create BME688 eagle footprint and schematic symbol
    [Qwiic_BME688.brd, Qwiic_BME688.sch]
2021-12-16 Schematic done
    [Qwiic_BME688.brd, Qwiic_BME688.sch]
2021-12-16 Updating schematic
    [Qwiic_BME688.brd, Qwiic_BME688.sch]
2021-12-17 Board routed
    [Qwiic_BME688.brd, Qwiic_BME688.sch]
2021-12-17 Buzzard labels
    [Qwiic_BME688.brd]
2021-12-21 Design review updates
    Schematic:
    * Add headers for CSB and SDO
    * Add NC jumper between CSB and 3.3V
    * Add 10k resistor for 3-way jumper
    * Replace I2C pullups with 2.2kohms
    * Increase the size of fiducials
    Board:
    * Change version number to v01
    [Qwiic_BME688.brd, Qwiic_BME688.sch]
2021-12-21 Design review updates - buzzard labels
    [Qwiic_BME688.brd]
2021-12-21 Engineering checklist
    [Qwiic_BME688.brd, Qwiic_BME688.sch]
2021-12-21 Double check
    Add note clarifying configuration to SPI mode.
    [Qwiic_BME688.sch]
2021-12-22 Update net names
    [Qwiic_BME688.brd, Qwiic_BME688.sch]
2021-12-22 Generate gerbers
    [Qwiic_BME688.GBL, Qwiic_BME688.GBO, Qwiic_BME688.GBP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]
2022-02-11 Fixed formatting of examples
    [Qwiic_BME688.brd, Qwiic_BME688.sch]
2022-02-11 Updates to hardware v02
    [Qwiic_BME688.brd, Qwiic_BME688.sch]
2022-02-11 Run new CAM for v02
    [Qwiic_BME688.GBL, Qwiic_BME688.GTL]
2022-02-11 Update version number
    [Qwiic_BME688.brd, Qwiic_BME688.sch]
2022-02-15 Design review changes
    * Add table for jumper selection
    * Nudge board name silk (on bottom) to avoid vias
    [Qwiic_BME688.brd, Qwiic_BME688.sch]
2022-02-15 Update the CSB label
    [Qwiic_BME688.brd]
2022-02-16 QC Double-check:
    * Add active low line to "CSB" net label in the schematic
    * Updated jumper selection table
    [Qwiic_BME688.brd, Qwiic_BME688.sch]
2022-02-16 Run CAM and Panelize
    [Qwiic_BME688-Panel.GBL, Qwiic_BME688-Panel.GBP, Qwiic_BME688-Panel.GBS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]
2022-02-16 Update BME688 schematic symbol
    * CSB pin to !CSB!
    [Qwiic_BME688.sch]
2022-04-07 Rename PICO/POCI net labels to CIPO/COPI
    [Qwiic_BME688.brd, Qwiic_BME688.sch]
2022-04-07 Rename PICO/POCI labels to SDO/SDI
    [Qwiic_BME688.brd, Qwiic_BME688.sch]
2022-04-07 Change I2C jumper notes on schematic
    [Qwiic_BME688.sch]
2022-05-05 File Cleanup
    Remove proto panel files
    [Qwiic_BME688.GBL, Qwiic_BME688.GBO, Qwiic_BME688.GBP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]

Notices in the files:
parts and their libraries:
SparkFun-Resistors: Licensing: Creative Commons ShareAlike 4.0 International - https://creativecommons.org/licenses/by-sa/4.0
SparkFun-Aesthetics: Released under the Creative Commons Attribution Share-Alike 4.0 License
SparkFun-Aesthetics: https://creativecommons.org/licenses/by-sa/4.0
